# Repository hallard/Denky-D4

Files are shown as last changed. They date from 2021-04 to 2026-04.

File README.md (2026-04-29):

# Denky D4 ESP32 Teleinfo

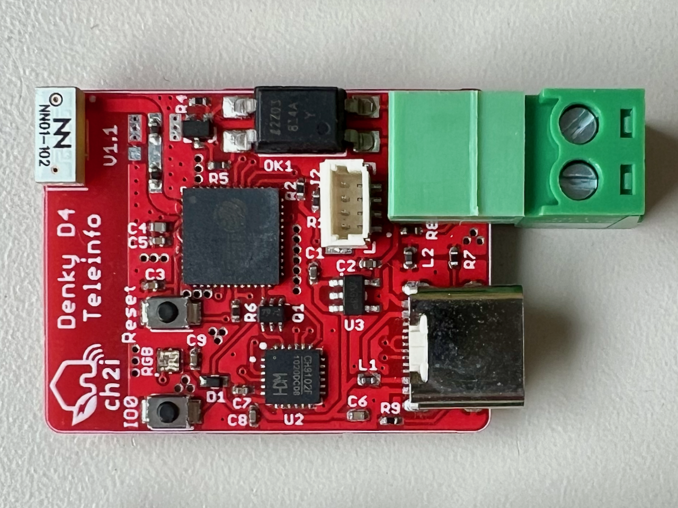
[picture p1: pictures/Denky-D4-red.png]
Denky D4


This board is used to get French energy meter called Teleinfo (AKA TIC) and has the following features:

- Steroid ESP32 using ESP32-PICO-V3-02 chip with 8Mb Flash and 2Mb PSRAM
- Serial to USB onboard converter
- Teleinfo Reader interface
- RGB User Led
- Blue LED to see if Teleinfo signal is received
- QWIIC/STEMMA I2C header sensors connector
- USB-C Connector

It is a plug and play board, nothing to solder or assemble.

# History

**New in v1.3a**

- Changed TIC trimmer from 1K to 2K
- Changed TIC Led (blue) resistor to decrease light intensity
- Placed easy cutting trace to disable Teleinfo Blue LED
- Added exposed pad for 5V and GND to external powering out of USB connector

**v1.3**

- Changed some silk for better reading

**v1.2**

- Replaced R3 by a trimmer to allow TIC sensitivity change without soldering resistors

**v1.1**

- Changed CPU now use ESP32-PICO-V3-02 with 8Mb Flash and 2Mb PSRAM
- Changed USB/SERIAL chip to CH9102 due to shortage
- Added footprint for U-FL connector for external antenna 
- Removed headers pins
- Reduced RGB LED size using SK6805-1515
- Added small visual blue LED on Teleinfo receive signal
- All components on same side (nothing on bottom side)

**v1.0**

- First fully working prototype

# Detailed Description

Look at the schematics for more informations, easy to understand. Wiring is as follow:

| Pin Function | ESP32-PICO | 
|  :--- |  :---:  |
| Téléinfo Rx  |  GPIO8  | 
| RGB Led |  GPIO14 | 
| I2C SDA |  GPIO21 | 
| I2C SDL |  GPIO22 | 

# Schematics

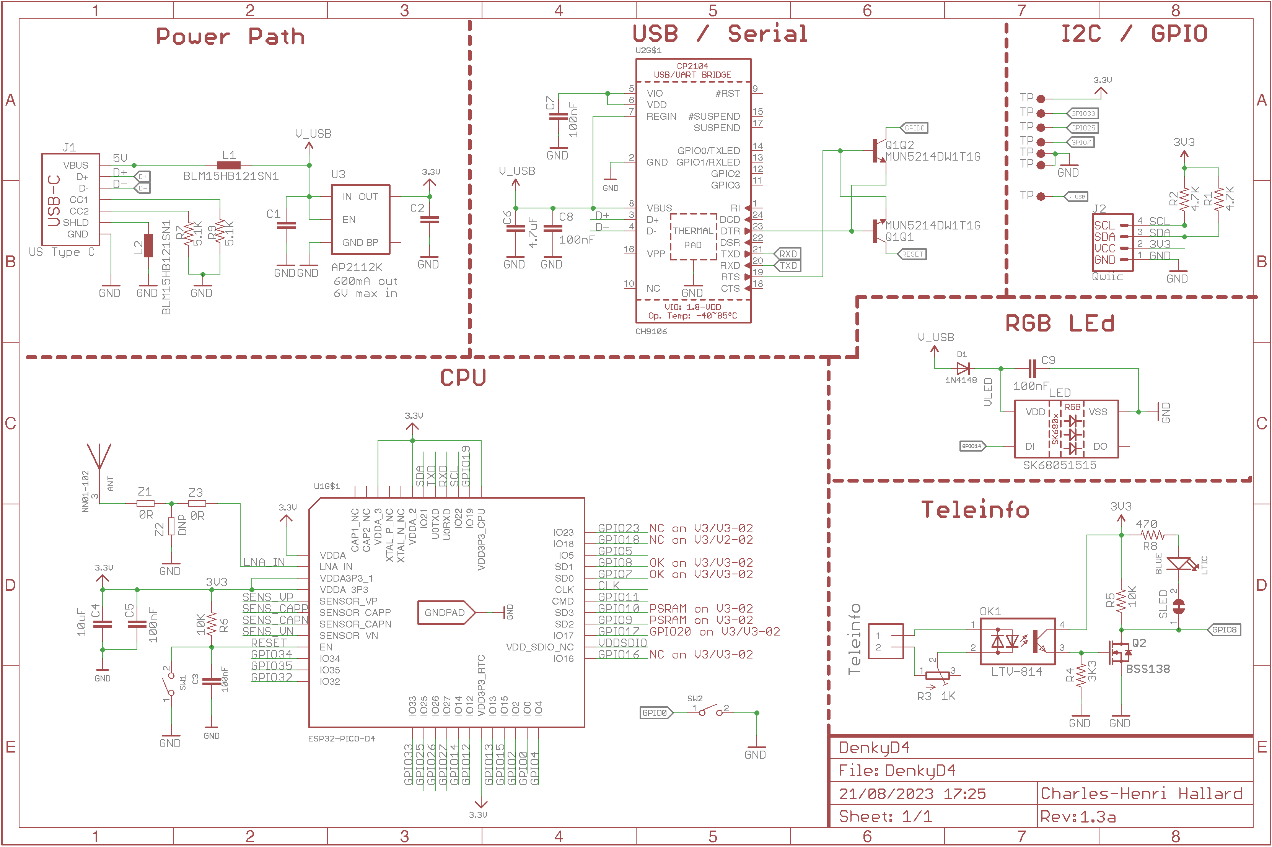
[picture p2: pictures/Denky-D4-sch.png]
Denky D4 Schematics


# Boards

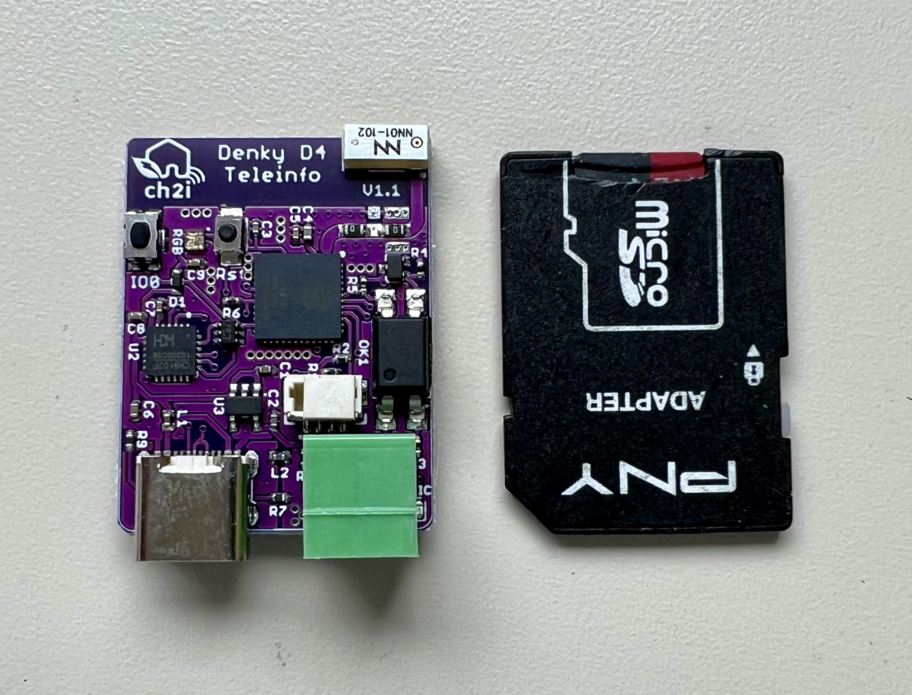
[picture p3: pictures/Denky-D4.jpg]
Denky D4 Size


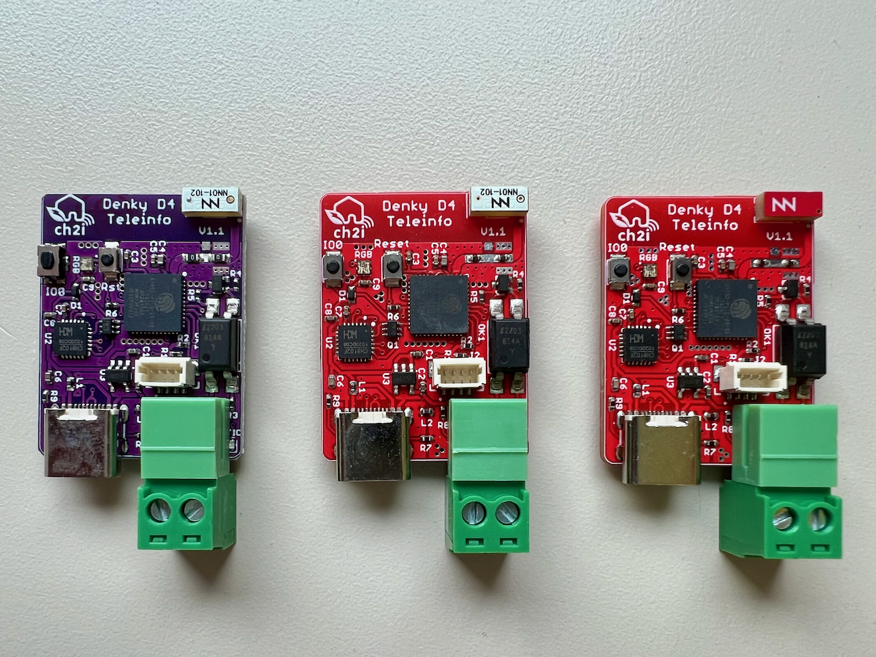
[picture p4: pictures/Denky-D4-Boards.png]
Denky D4 Boards


# Firmware 

It's compatible with Arduino IDE, Visual Studio Code and also Micro Python since this board use same CPU than Adafruit [QT-PY-ESP32-PICO](https://learn.adafruit.com/adafruit-qt-py-esp32-pico)

You can write your own and use with [LibTeleinfo](https://github.com/hallard/LibTeleinfo) library I wrote if you want to get rid of driving teleinfo stuff (chekout some [examples](ttps://github.com/hallard/LibTeleinfo/tree/master/examples)).

## Tasmota

But I strongly suggest using amazing [Tasmota](https://tasmota.github.io/docs/) firmware, all is already done and well done.

Please check Teleinfo official tasmota [documentation](https://tasmota.github.io/docs/Teleinfo/) so see how to configure your device depending on smartmeter type and what options you need.

### Nicolas's builds

Nicolas @NicolasBernaerts has made awesome changes on Tasmota to be able to show graph of consumption, history and other great features such has:

- Ecowatt server to publish RTE Ecowatt signals
- TCP server to live stream teleinfo data
- FTP server to easily retrieve graph data

You can find more information on his dedicated [repo](https://github.com/NicolasBernaerts/tasmota/tree/master/teleinfo) and also ready made build for this Denky D4 board.

### Tasmota Unofficial builds

Teleinfo is not member of official Tasmota builds. So you need to build your own with `USE_TELEINFO` define. 
But Tasmota team agreed it's not simple to build for end users, and they now provide unofficial build that follow developement branch, this mean you always have an up to date build with latest code available. Of course we added Teleinfo (ESP8266 and ESP32) builds in this unofficial build process so you have nothing to install and compile/link (building). You can't go easier.

And as a cherry on the cake, easy flasher tools (web version and executable one) will present Teleinfo firmware so you are able to flash teleinfo firmware in less than 1 minute. You can check detail [here](https://github.com/Jason2866/Tasmota-specials) but here how to do that.

- Launch [Web Flasher here](https://jason2866.github.io/Tasmota-specials/) 
- Select Teleinfo 
- Select Serial port, and click `install`



Once done something like that



After flashed, you should now see a new access point named `tasmota_aabbcc_xxxx` where you can connect to configure your WiFi for the device to connect on.

Alternatively, if you connect serial console and reset the device you should see Serial logs like that
```
00:00:00.003 HDW: ESP32-D0WDQ6 
00:00:00.037 UFS: FlashFS mounted with 308 kB free
00:00:00.109 CFG: Loaded from File, Count 12
00:00:00.124 QPC: Count 1
00:00:00.257 CFG: no '*.autoconf' file found
00:00:00.263 BRY: Berry initialized, RAM used=3620
00:00:00.282 BRY: no 'preinit.be'
00:00:00.291 Project tasmota - Tasmota Version 10.0.0.3(teleinfo)-2_0_1_1(2021-11-30T14:22:47)
00:00:00.379 BRY: no 'autoexec.be'
00:00:00.447 WIF: WifiManager active for 3 minutes
00:00:01.139 HTP: Web server active on tasmota-090F8C-3980 with IP address 192.168.4.1
00:00:06.827 QPC: Reset
```

If you want to deep into this process or just curious, you can check out it's [here](https://github.com/Jason2866/Tasmota-specials)

:memo: If you have some issues flashing with Web Flasher, do not hesitate to use another awesome tool [ESP Flasher](https://github.com/Jason2866/ESP_Flasher), with this one you can see exactly what's going on in case of issue because it has built in console. Usefull also after reboot of the device because console still active. This is the one I'm using day by day. In this case you need to download firmware to flash first [here](https://github.com/Jason2866/Tasmota-specials/tree/firmware/firmware/tasmota/other). Download firmware `tasmota-teleinfo`

You can take a look on `autoconf` [folder](https://github.com/tasmota/autoconf/tree/main/raw/esp32/Wemos_Teleinfo) to see some of init commands used on Denky D4.

:memo: Don't forget to reset Energy counters on first boot with console command `EnergyTotal 0` if you have erratic values. 

### I2C Display

You can add fancy I2C display (or even I2C sensors), using the on board QWIIC sensor, please refer to section [I2C Display](https://github.com/hallard/WeMos-TIC/blob/master/README.md#i2c-display).

### Autoconf 

Another awesome feature of Tasmota is the ability to download configuration profile, and guess what, we done it for Denky D4, just go to configuration option, select Autoconfig and then choose in the list `Denky D4 V1.1` and here you are, ne need to copy/paste template, it's done by autoconfig.
If you want to deep into this process or just curious, you can check out it's [here](https://github.com/tasmota/autoconf)

### Tasmota template

I strongly suggest using awesome Tamsota autoconf feature but if you need Tasmota template for Denky D4, here it it

#### V1.1 and up
```json
{"NAME":"Denky D4 (v1.1)","GPIO":[32,0,0,0,1,0,0,0,0,1,1376,1,0,0,0,0,0,640,608,0,0,0,0,0,0,0,5632,0,0,0,0,0,0,0,0,0],"FLAG":0,"BASE":1}
```

#### V1.0
```json
{"NAME":"Denky D4 (v1.0)","GPIO":[32,0,0,0,1,0,0,0,0,1,0,1,0,0,0,0,0,640,608,0,0,450,449,448,0,0,5632,0,0,0,0,0,0,0,0,0],"FLAG":0,"BASE":1}
```

## Berry Scripting 

Now you can personalize code with [Berry language](https://tasmota.github.io/docs/Berry/). Check out some Berry samples [here](https://github.com/arendst/Tasmota/blob/development/tasmota/berry/examples/)

You can do that by going to Berry console from Tasmota WEB user interface.

### Drive RGB LED depending on actual power

Here is a Berry example, goal is to follow real time consumption driving on board RGB Led depending on current Power consumption (low green then going to red when reaching maximum current of your contract)

```python
#-
# example of using Berry script to change the led color
# accordingly to power consumption
# using Denky or WeMos Teleinfo (French Teleinfo reader)
-#

#- define the global symbol for reference -#
runcolor = nil

def runcolor()
  var max_contrat = 30 # contrat 30A
  var i = energy.current
  #print(i)
  var red = tasmota.scale_uint(int(i), 0, max_contrat, 0, 255)
  var green = 255 - red
  var channels = [red, green, 0]
  light.set({"channels":channels, "bri":64, "power":true})
  tasmota.set_timer(2000, runcolor)
end

#- run animation -#
runcolor()
```

### Send data to Emoncms with Berry 

What's magic with Berry is the ability to do basic stuff with data, in this example we will intercept MQTT send message by Energy driver, do some calc and send data to Emoncms every 15 seconds and also to drive RGB Led from Green (low load) to Red (approach max subscription)

Modifiy API key with your, and copy paste the following code into Berry Console. Tst and validate if all is okay for you.

Once all is fine, you paste the code into a file named `autoexec.be` on the Tasmota Filesystem so it will be executed each time Tasmota device starting.

#### Mode Historique (contrat heures creuses)

```python
import json

var api_url = "https://emoncms.org/input/post"
var api_key = "YOUR_EMON_API_WRITE_KEY"
var node_name = "NODE_NAME"
var post_every = 15000 # post evert 15 seconds
var payload = {}

def send_emoncms()
  # Convert JSON object to string 
  var obj_json = json.dump(payload)

  # Create URL to call
  var param="?fulljson="+obj_json + "&node="+node_name + "&apikey="+api_key 
  # Post Data to EMONCMS
  var cl = webclient()
  cl.begin( api_url + param)
  var r =  cl.GET()
  tasmota.set_timer(post_every, send_emoncms)
end

def setcolor(iinst, isousc)
  var red = tasmota.scale_uint(iinst, 0, isousc, 0, 255)
  var green = 255 - red
  var channels = [red, green, 0]
  light.set({"channels":channels, "bri":64, "power":true})
end

# set global payload the field we need
def rule_tic(value, trigger)
  # Got Heures Creuses contract so I will calculate total consumption
  # adding Heures Creuses (HCHC) + Heures Pleines (HCHP) and create new value for emoncms 
  # Change label depending on name for your contract type
  var htot = value['HCHP'] + value['HCHC'] # mode historique
  # Create new value HTOT converted to kWH
  payload['HTOT'] = htot / 1000.0
  # Calculate current percent Load 
  var iinst = value['IINST']  # mode historique
  var isousc= value['ISOUSC'] # mode historique

  if iinst != nil && isousc != nil 
    # Drive RGB LED
    setcolor(iinst, isousc)
    if isousc > 0
      load = 100 * iinst / isousc
      payload['LOAD'] = load
    end
  end

  # Set values we need to send to emoncms
  payload['ADCO']  = value['ADCO']
  payload['HCHP']  = value['HCHP']
  payload['HCHC']  = value['HCHC']
  payload['ISOUSC']= isousc
  payload['PAPP']  = value['PAPP']
  payload['IINST'] = iinst

end

def start()
  # Callback on each frame interception
  tasmota.add_rule("TIC",rule_tic)
  # fire 1st post in 5s 
  tasmota.set_timer(5000, send_emoncms)
end

# delay start to have time to get full frame
tasmota.set_timer(10000, start)

```

#### Mode Standard (contrat heures creuses)

```python
import json

var api_url = "https://emoncms.org/input/post"
var api_key = "YOUR_EMON_API_WRITE_KEY"
var node_name = "NODE_NAME"
var post_every = 15000 # post evert 15 seconds
var payload = {}

def send_emoncms()
  # Convert JSON object to string 
  var obj_json = json.dump(payload)

  # Create URL to call
  var param="?fulljson="+obj_json + "&node="+node_name + "&apikey="+api_key 
  # Post Data to EMONCMS
  var cl = webclient()
  cl.begin( api_url + param)
  var r =  cl.GET()
  tasmota.set_timer(post_every, send_emoncms)
end

def setcolor(iinst, isousc)
  var red = tasmota.scale_uint(iinst, 0, isousc, 0, 255)
  var green = 255 - red
  var channels = [red, green, 0]
  light.set({"channels":channels, "bri":64, "power":true})
end

# set global payload the field we need
def rule_tic(value, trigger)
  # Got Heures Creuses contract so I will calculate total consumption
  # Calculate current percent Load 
  var iinst = value['IRMS1']  
  var isousc= value['PREF']*5 

  if iinst != nil && isousc != nil 
    # Drive RGB LED
    setcolor(iinst, isousc)
    if isousc > 0
      load = 100 * iinst / isousc
      payload['LOAD'] = load
    end
  end

  # Here I keep name of historique mode
  payload['ADCO']  = value['ADSC']
  payload['HTOT']  = value['EAST'] / 1000 # I need kWh
  payload['HCHP']  = value['EASF01']
  payload['HCHC']  = value['EASF02']
  payload['ISOUSC']= isousc
  payload['PAPP']  = value['SINSTS']
  payload['IINST'] = iinst

end

def start()
  # Callback on each frame interception
  tasmota.add_rule("TIC",rule_tic)
  # fire 1st post in 5s 
  tasmota.set_timer(5000, send_emoncms)
end

# delay start to have time to get full frame
tasmota.set_timer(10000, start)

```

### Custom WEB Interface

If you are not happy with values on the WEB interface you can totaly change them to fit your needs.

You can add new values to display or disable all values displayed and use you own or even some calculated ones.

To disable all current values displayed please use the following command in console (not the berry one)

```
backlog0 WebSensor0 0 ; WebSensor1 0 ; WebSensor2 0 ; WebSensor3 0
```

Then you can add Teleinfo driver (this one as example) into a file named `teleinfo.be`

This is just an example please fill it to your needs. This one display Total `EAST` index, `URMS1` and `IRMS1` on web interface

```python
# Teleinfo driver written in Berry
# Support for Teleinfo custom values from choosen fields returned by smart meter
 
class TELEINFO: Driver

  # Global var Needed
  var east
  var irms
  var urms

  def init()
    # initialize globals

    # Don't display original sensors on WebUI, we want just our ones
    tasmota.cmd("backlog0 WebSensor0 0 ; WebSensor1 0 ; WebSensor2 0 ; WebSensor3 0")

    # create rules to trigger when Teleinfo values updates 
    # Use Teleinfo Etiquette Names to get whatever value you need
    tasmota.add_rule("TIC#EAST", /value -> self.trigger_east(value))
    tasmota.add_rule("TIC#IRMS1", /value -> self.trigger_irms(value))
    tasmota.add_rule("TIC#URMS1", /value -> self.trigger_urms(value))
  end

  def trigger_east(index)
    self.east = index
  end

  def trigger_irms(i)
    self.irms = i
    # DEBUG print("irms:", i)
  end

  def trigger_urms(u)
    self.urms = u
    # DEBUG print("urms:", u)
  end

  # trigger a read every second 
  def every_second()
    # DEBUG print("sensors:",tasmota.read_sensors())
  end

  # display sensor value in the web UI
  def web_sensor()
    import string
    var msg = string.format(
            "{s}Consommation{m}%d Wh{e}"
            "{s}Tension RMS{m}%d V{e}"
            "{s}Intensité RMS{m}%d A{e}", 
             self.east, self.urms, self.irms )

    tasmota.web_send_decimal(msg)
  end

end

# Instantiate the driver
teleinfo = TELEINFO()
# add it to Tasmota
tasmota.add_driver(teleinfo)

```

Then you need to load and start it into your `autoexec.be` file. just add followin at the end of the file

```python
# Auto start teleinfo driver
load("teleinfo.be")
```

#### Here how it looks like

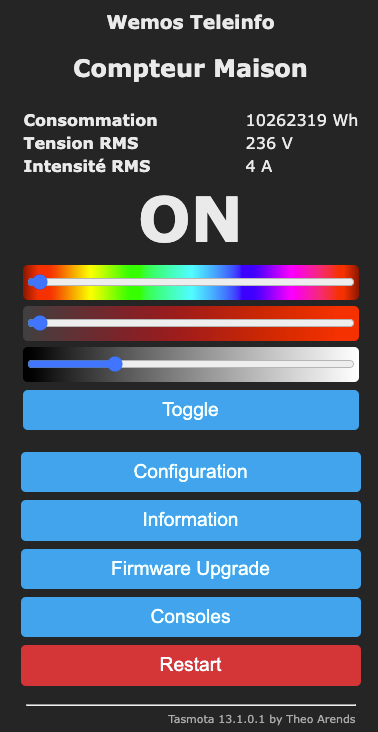
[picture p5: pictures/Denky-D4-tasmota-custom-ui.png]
Denky D4 Custom User Interface


### ESPHome

Denky D4 is fully compatible with ESPHome, find below a sample for Historique with Heures Creuses contract.
Pasting this code without knowing your contract and teleinfo mode of your linky will just NOT work, you need to adpat to your needs        

Read and get full working samples on @mathieucarbou [gist](https://gist.github.com/mathieucarbou/886d2a6f5c0b51bb261d6a1329beb08d#file-readme-md)

`denky-d4.yaml`

```yaml
# This code comes from @mathieucarbou many thanks to him
# you need to check it out and adapt depending on your needs
# https://gist.github.com/mathieucarbou/886d2a6f5c0b51bb261d6a1329beb08d#file-readme-md
# You need to knw wich mode your smart meter is (HISTORIQUE or STANDARD)
# and which contract you have to adjust sensor name to grab correct sensor information

esphome:
  name: denky-d4
  friendly_name: Denky D4

esp32:
  board: denky_d4
  framework:
    type: esp-idf

logger:
#  level: WARN

wifi:
  ssid: !secret wifi_ssid
  password: !secret wifi_password

api:

ota:
  platform: esphome

# Denky D4 RX pin
uart:
  rx_pin:
    number: GPIO8
    ignore_pin_validation_error: true
  baud_rate: 1200
  parity: EVEN
  data_bits: 7
  stop_bits: 1

binary_sensor:
  - platform: status
    id: teleinfo_status
    name: "Teleinfo Status"

button:
  - platform: restart
    name: "Teleinfo Restart"

# https://esphome.io/components/sensor/teleinfo.html
teleinfo:
  update_interval: 5s
  historical_mode: true

# Web Server: https://esphome.io/components/web_server.html
web_server:
  local: true
  port: 80    
    #   auth:
    #     username: !secret esphome_web_server_username
    #     password: !secret esphome_web_server_password

# https://esphome.io/components/sensor/index.html
sensor:
  # WiFi
  - platform: wifi_signal
    name: "WiFi Signal"
    unit_of_measurement: dB
    device_class: signal_strength
    accuracy_decimals: 0
    update_interval: 60s
  # Uptime
  - platform: uptime
    name: "Uptime"
    unit_of_measurement: s
    device_class: duration
    accuracy_decimals: 0
    update_interval: 60s

#######################################################
#      HISTORIQUE with Heures Creuses Contract        #
# Pasting this code without knowing your contract and #
# teleinfo mode of your linky will just NOT work      #
# YOu will need to adpat to your needs                #
#######################################################

  # Intensité souscrite
  - platform: teleinfo
    tag_name: "ISOUSC"
    name: "Intensité souscrite"
    unit_of_measurement: A
    device_class: current
    state_class: measurement
  # Index option Base
  #- platform: teleinfo
  # tag_name: "BASE"
  # name: "Index Base"
  # unit_of_measurement: kWh
  # device_class: energy
  # state_class: total_increasing
  # accuracy_decimals: 3
  # filters:
  #   - multiply: 0.001
  # Index option HP/HC
  - platform: teleinfo
    tag_name: "HCHC"
    name: "Index HC"
    unit_of_measurement: kWh
    device_class: energy
    state_class: total_increasing
    accuracy_decimals: 3
    filters:
      - multiply: 0.001
  - platform: teleinfo
    tag_name: "HCHP"
    name: "Index HP"
    unit_of_measurement: kWh
    device_class: energy
    state_class: total_increasing
    accuracy_decimals: 3
    filters:
      - multiply: 0.001

  # Intensité Instantanée (monophasé)
  - platform: teleinfo
    tag_name: "IINST"
    name: "Intensité Instantanée"
    unit_of_measurement: A
    device_class: current
    state_class: measurement
  # Avertissement de Dépassement De Puissance Souscrite
  - platform: teleinfo
    tag_name: "ADPS"
    name: "Intensité Instantanée Dépassement"
    unit_of_measurement: A
    device_class: current
    state_class: measurement
  # Intensité maximale appelée (monophasé)
  - platform: teleinfo
    tag_name: "IMAX"
    name: "Intensité Maximale"
    unit_of_measurement: A
    device_class: current
    state_class: measurement
  # Puissance apparente
  - platform: teleinfo
    tag_name: "PAPP"
    name: "Puissance Apparente"
    unit_of_measurement: VA
    state_class: measurement
    device_class: apparent_power

# https://esphome.io/components/text_sensor/index.html
text_sensor:
  # Adresse du compteur
  - platform: teleinfo
    tag_name: "ADCO"
    name: "Adresse"
  # Option tarifaire choisie
  - platform: teleinfo
    tag_name: "OPTARIF"
    name: "Option Tarifaire"
  # Période Tarifaire en cours
  - platform: teleinfo
    tag_name: "PTEC"
    name: "Période Tarifaire"
  # Couleur du lendemain
  - platform: teleinfo
    tag_name: "DEMAIN"
    name: "Couleur Demain"
  # Horaire Heures Pleines Heures Creuses
  - platform: teleinfo
    tag_name: "HHPHC"
    name: "Horaire HP/HC"
  # Mot d'état du compteur
  - platform: teleinfo
    tag_name: "MOTDETAT"
    name: "Mot d'état"

```

# Support and discussion

If you have any issue or just want to discuss on this project, please use community [forum](https://community.ch2i.eu/category/20)

# License



This work is licensed under a [Creative Commons Attribution-NonCommercial-ShareAlike 4.0 International License](https://creativecommons.org/licenses/by-nc-sa/4.0/)    
If you want to do commercial stuff with this project, please contact [CH2i company](https://ch2i.eu/en#support) so we can organize an simple agreement.

# Lazy building your own? 

You can order this module (V1.3a only) fully assembled with some extra on [tindie][1] or on [Lectronz](https://lectronz.com/products/denky-d4).

European customers may prefer ordering on Lectronz, which offers additional payment methods and pricing in Euros.





# Misc

See news and other projects on my [blog][2] 
 
[1]: https://www.tindie.com/products/25467/
[2]: https://hallard.me

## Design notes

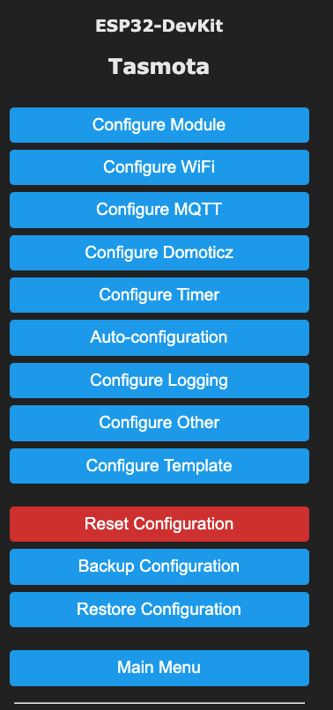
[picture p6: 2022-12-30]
pictures/Denky-D4-tasmota-config.png

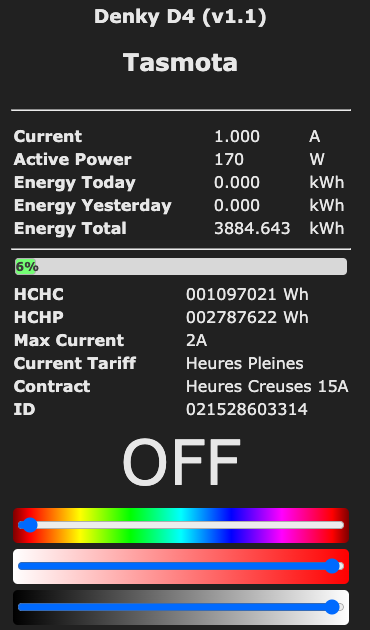
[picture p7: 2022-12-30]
pictures/Denky-D4-tasmota-ok.png

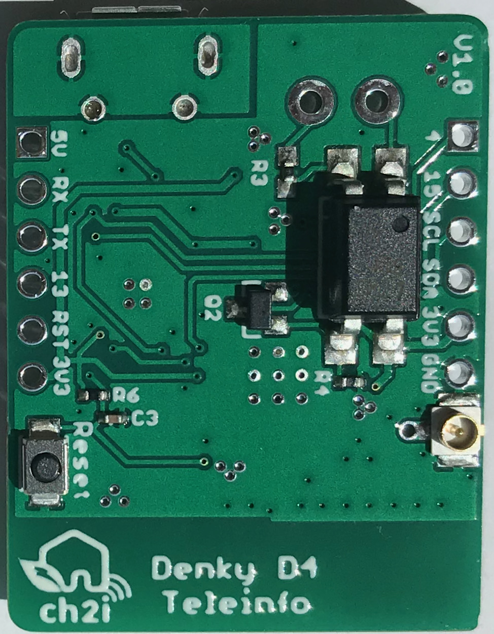
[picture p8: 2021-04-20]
pictures/denky-d4-bot.jpg

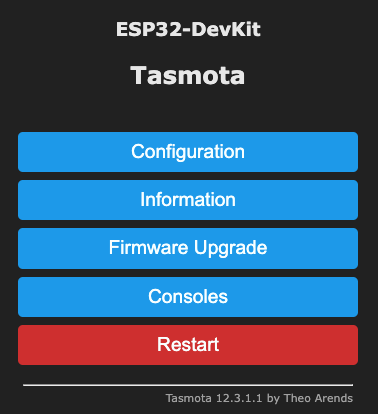
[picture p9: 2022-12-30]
pictures/Denky-D4-tasmota-boot.png

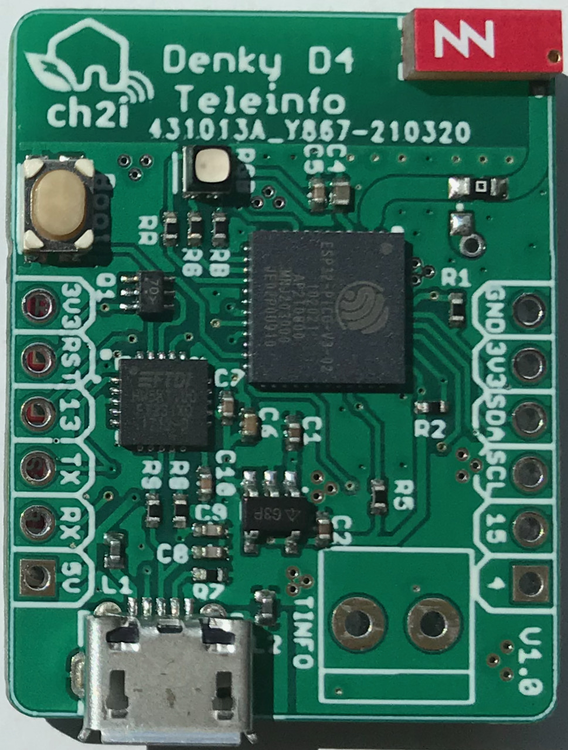
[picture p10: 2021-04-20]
pictures/denky-d4-top.jpg

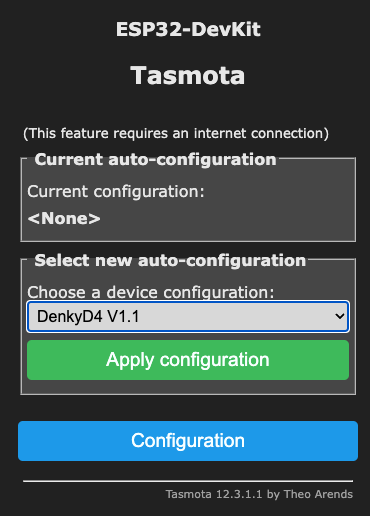
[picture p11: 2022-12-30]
pictures/Denky-D4-tasmota-auto-config.png

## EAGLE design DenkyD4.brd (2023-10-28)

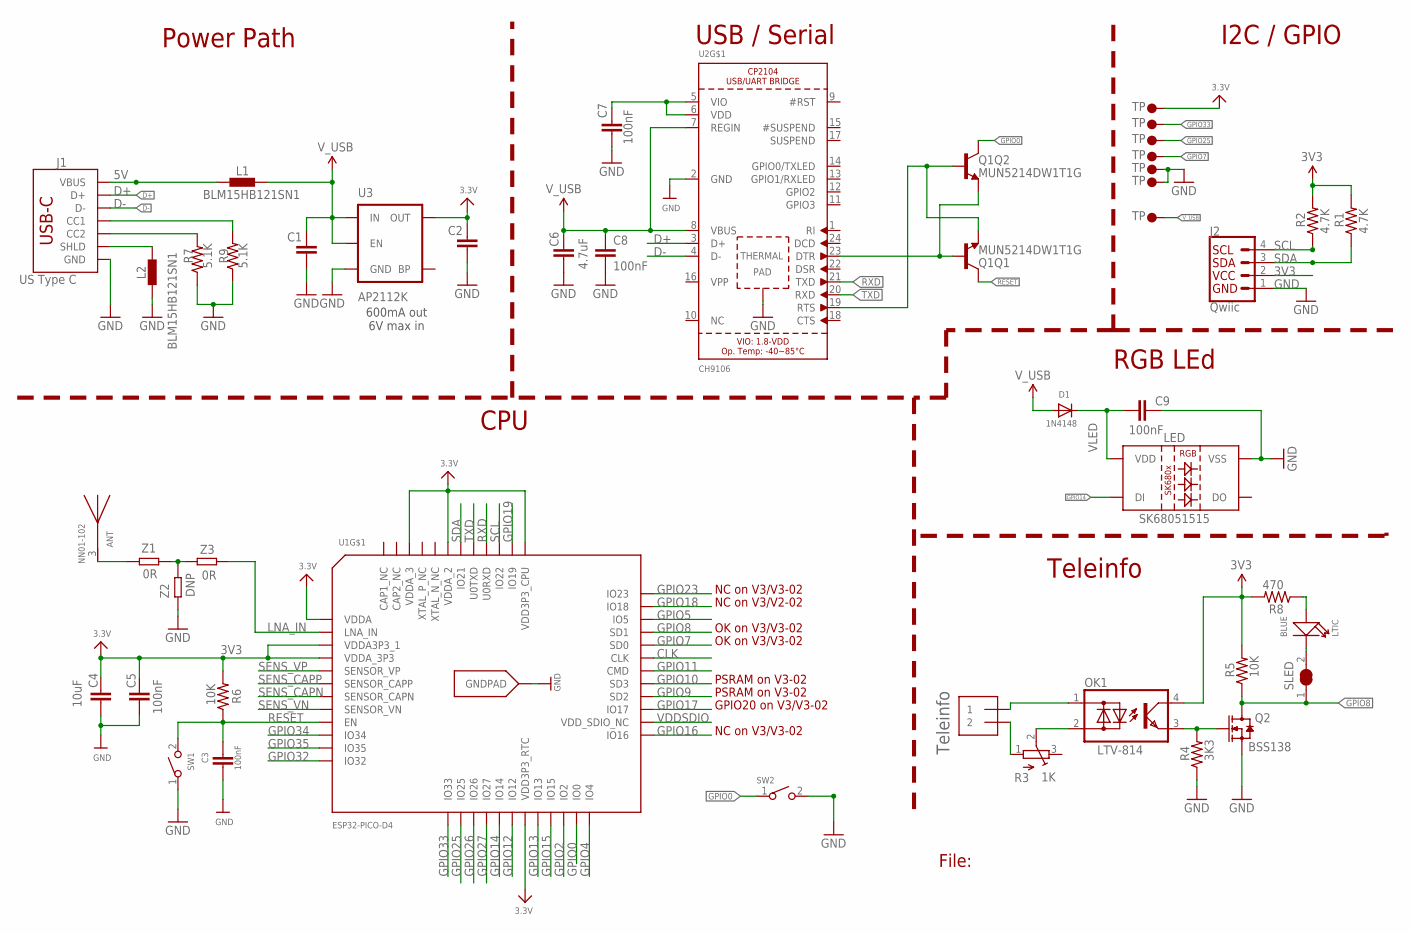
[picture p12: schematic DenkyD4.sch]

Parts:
ANT: NN01-102; XCVR_NN03-320
C1, C2: 1.0uF; 0402-CAP-OK
C3, C5, C7, C8, C9: 100nF; 0402-CAP-OK
C4: 10uF; 0402-CAP-OK
C6: 4.7uF; 0402-CAP-OK
D1: 1N4148; SOD-523
J1: US Type C; USB-C-16P-4LAYER-ISOLATED
J2: Qwiic; JST04_1MM_VERT
J3: KF2EDGR-3.81-2P; 1X2-3.5MM
L1, L2: BLM15HB121SN1; 0402
LED: SK68051515; SK6805-1515
LTIC: BLUE; LED-0402
OK1: LTV-814; DIL4-SMD
Q1: MUN5214DW1T1G; DUAL_NPN_SC70-6
Q2: BSS138; SOT-323-3
R1, R2: 4.7K; 0402-RES
R3: 1K; TC33X
R4: 3K3; 0402-RES
R5, R6: 10K; 0402-RES
R7, R9: 5.1K; 0402-RES
R8: 470; 0402-RES
SLED: SOLDERJUMPER_CLOSED; SOLDERJUMPER_CLOSEDWIRE
SW1: RESET; C498294
SW2: SMD-BUTTON(2P-3.0X2.5X1.2+0.4MM); C498294
TGG, TGG1, TGG2: TP3; TP60_BOT
TP3: TP3; TP60_BOT
U1: ESP32-PICO-D4; PICO-D4-QFN48
U2: CH9106; QFN24_4MM_SMSC
U3: AP2112K; SOT23-5
U$3, U$6, U$11: TP3; TP60_BOT
Z1, Z3: 0R; 0603-MATCHNET
Z2: DNP; 0603-MATCHNET

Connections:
3V3: C2.1, C4.1, C5.1, J2.2, OK1.4 (C), R1.2, R2.2, R5.2, R6.2, R8.2, TP3.P$1, U1.1 (VDDA), U1.3 (VDDA3P3_1), U1.4 (VDDA_3P3), U1.19 (VDD3P3_RTC), U1.37 (VDD3P3_CPU), U1.43 (VDDA_2), U1.46 (VDDA_3), U3.5 (OUT)
5V: J1.VBUS1 (VBUS), J1.VBUS2 (VBUS), L1.1
CLK: U1.31 (CLK)
D+: J1.A6 (D+), J1.B6 (D+), U2.3 (D+)
D-: J1.A7 (D-), J1.B7 (D-), U2.4 (D-)
DTR: Q1.1 (E), Q1.5 (B), U2.23 (DTR)
GND: C1.2, C2.2, C3.2, C4.2, C5.2, C6.1, C7.1, C8.2, C9.2, J1.GND, J1.GND2 (GND), J2.1, L2.2, LED.4 (VSS), Q2.2 (S), R4.1, R7.1, R9.1, SW1.1, SW2.2, TGG.P$1, TGG1.P$1, U1.EXP (GNDPAD), U2.2 (GND), U2.THERM (TP), U3.2 (GND), Z2.2
GPIO0: Q1.6 (C), SW2.1, U1.23 (IO0)
GPIO2: U1.22 (IO2)
GPIO4: U1.24 (IO4)
GPIO5: U1.34 (IO5)
GPIO7: U1.32 (SD0), U$3.P$1
GPIO8: Q2.3 (D), R5.1, SLED.1, U1.33 (SD1)
GPIO9: U1.28 (SD2)
GPIO10: U1.29 (SD3)
GPIO11: U1.30 (CMD)
GPIO12: U1.18 (IO12)
GPIO13: U1.20 (IO13)
GPIO14: LED.1 (DI), U1.17 (IO14)
GPIO15: U1.21 (IO15)
GPIO16: U1.25 (IO16)
GPIO17: U1.27 (IO17)
GPIO18: U1.35 (IO18)
GPIO19: U1.38 (IO19)
GPIO23: U1.36 (IO23)
GPIO25: U1.14 (IO25), U$11.P$1
GPIO26: U1.15 (IO26)
GPIO27: U1.16 (IO27)
GPIO32: U1.12 (IO32)
GPIO33: U1.13 (IO33), U$6.P$1
GPIO34: U1.10 (IO34)
GPIO35: U1.11 (IO35)
LNA_IN: U1.2 (LNA_IN), Z3.2
unnamed: Z1.1, Z2.1, Z3.1
unnamed: OK1.3 (E), Q2.1 (G), R4.2
unnamed: OK1.2 (AC2), R3.2 (S)
unnamed: J3.1, OK1.1 (AC1)
unnamed: J3.2, R3.1 (A)
unnamed: LTIC.-, SLED.2
unnamed: C7.2, U2.5 (VIO), U2.6 (VDD)
unnamed: LTIC.+, R8.1
unnamed: J1.A5 (CC1), R9.2
unnamed: J1.B5 (CC2), R7.2
unnamed: ANT.3, Z1.2
RESET: C3.1, Q1.3 (C), R6.1, SW1.2, U1.9 (EN)
RTS: Q1.2 (B), Q1.4 (E), U2.19 (RTS)
RXD: U1.40 (U0RXD), U2.21 (TXD)
SCL: J2.4, R2.1, U1.39 (IO22)
SDA: J2.3, R1.1, U1.42 (IO21)
SENS_CAPN: U1.7 (SENSOR_CAPN)
SENS_CAPP: U1.6 (SENSOR_CAPP)
SENS_VN: U1.8 (SENSOR_VN)
SENS_VP: U1.5 (SENSOR_VP)
SHIELD: J1.SHLD1 (SHLD), J1.SHLD2 (SHLD), J1.SHLD3 (SHLD), J1.SHLD4 (SHLD), J1.SHLD5 (SHLD), J1.SHLD6 (SHLD), J1.SHLD7 (SHLD), J1.SHLD8 (SHLD), L2.1
TXD: U1.41 (U0TXD), U2.20 (RXD)
VDDSDIO: U1.26 (VDD_SDIO_NC)
VLED: C9.1, D1.K (C), LED.2 (VDD)
V_USB: C1.1, C6.2, C8.1, D1.A, L1.2, TGG2.P$1, U2.7 (REGIN), U2.8 (VBUS), U3.1 (IN), U3.3 (EN)

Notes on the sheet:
File:
Teleinfo
I2C / GPIO
600mA out 6V max in
GPIO20 on V3/V3-02
NC on V3/V3-02
PSRAM on V3-02
OK on V3/V3-02
NC on V3/V2-02
RGB LEd
USB / Serial
Power Path
CPU

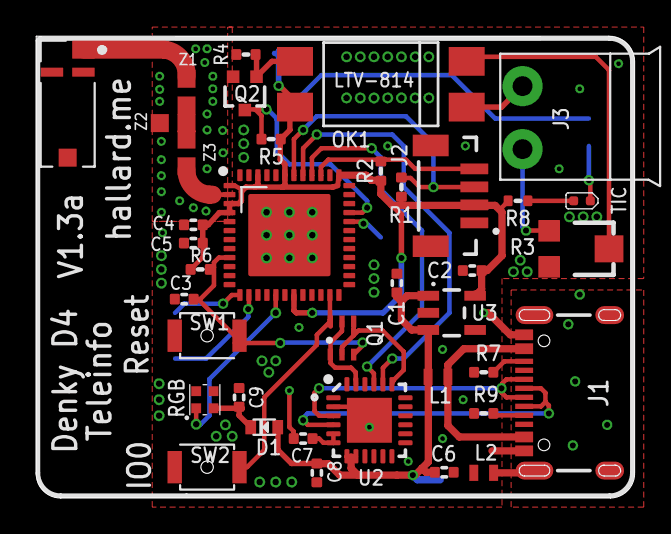
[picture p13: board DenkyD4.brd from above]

Board: 2 copper layers, 33.2 x 25.7 mm, 46 parts (1 on the bottom side), 33 nets.

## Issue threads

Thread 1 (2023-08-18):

Auto alimentation

cosygarcia, 2023-08-18:
Bonjour Charles,
Félicitation pour cette belle réalisation qu'est le Denky D4.
Dans le cas d’un compteur Linky à l’extérieur de la maison comment faudrait-il faire pour utiliser la borne A du Linky pour alimenter le Denky D4 ?
Merci d’avance

hallard, 2023-10-28:
Bonjour,
C'est en cours avec Jérôme on travaille sur une nouvelle version :-)
https://gricad-gitlab.univ-grenoble-alpes.fr/ferrarij/winky

Closed 2023-10-28.

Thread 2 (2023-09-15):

Compat avec ESPHome

alucryd, 2023-09-15:
Bonjour,

Je viens juste de commander un D4, il semble que le bug suivant pourrait être gênant si je flashe ESPHome dessus: https://github.com/esphome/issues/issues/4151

Je peux répliquer dans l'éditeur, par contre si je sélectionne `adafruit_qtpy_esp32` comme board je n'ai plus d'erreur. Est-ce que ça a déja pu être testé, histoire que je ne fasse pas n'importe quoi ?

hallard, 2023-10-28:
Bonjour oui je crois que la reponse est dans l'issue originale.

Sinon qq info ici et la  https://forum.hacf.fr/t/separer-les-heures-creuses-et-pleines-en-fonction-d-un-sensor/20164/17

Closed 2023-10-28.

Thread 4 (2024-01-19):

Power from Linky A Slot

xav-git, 2024-01-19:
Hello,
I did not find any information whether this module could be plugged directly on Linky  "A" pin in order to benefit from the power supply provided by linky power meters.

I assume that an independant power source would be needed to power this module, am I right ?
Regards.

hallard, 2024-01-19:
Hi,
you're correct, Denky D4 needs a power supply because Tasmota is running all time (real time reading/sending data).

Powered by A pin is not possible with Denky D4 because it's not it's main function but also because hardware is not designed for. Even if it was designed for, working mode would be different, sleeping until we have enough power, then connect to wifi send data and go to sleep again.
We're working on Winky version this one would be powered with A pin
https://miniprojets.net/index.php/2022/02/04/winky-version-2-open-source-projet-pour-linky-avec-wifi/

Closed 2024-02-01.

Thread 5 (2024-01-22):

Missing sensors in HA

jsapede, 2024-01-22:
Hello,

installed this weekend denky D4 and seems to work well with homeassistant.

Howevoer, in HA i got some sensors always to Zero :

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

looks like power is correctly upstreramed, an i build my own energy counters but what to do with those zero counters  ? is it normal ? its there a manipulation to do on the linky ?

Jimmy

hallard, 2024-08-19:
@jsapede sorry about delay, for home assistant you can use excellent firmware done by Nicolas, Home Assistant integration is native as others.
check this out https://github.com/NicolasBernaerts/tasmota/tree/master/teleinfo

Closed 2024-08-19.

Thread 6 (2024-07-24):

Denky power issue

nyok92, 2024-07-24:
Hi @hallard
My denky D4 board v1.3a bought in November 2023 is not powering up anymore. (no led lit, not detected with computer)
Do you have any tips to troubleshoot ? known issue ?
thanks

nyok92, 2024-07-24:
negative ! all is right sorry

Closed 2024-07-24.

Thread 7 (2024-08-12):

compatibility with Linky?

Abdull, 2024-08-12:
Dear Charles,

sorry if noob question (smart meters are implemented differently in Germany):

* is the Denky D4 compatible with French Linky boxes?
* if so, how would the be connected to a Linky box? Via connecting cables to the Linky box (when taking of its green cover) at its lower right corner? Could you provide example photos?
* Using a Teleinfo-enabled Tasmota firmware, is the Denky-D4 already self-sufficient for reporting current and historical data ,e.g. by visiting its own web interface? Or does it require a further separate home automation application, e.g. a dedicated Home Assistant installation, which connects to the Denky-D4 and pulls data?

Thanks in advance

hallard, 2024-08-19:
Hi @Abdull

>is the Denky D4 compatible with French Linky boxes?

yes fully compatible,

> if so, how would the be connected to a Linky box?

for pin it needs to be connected to pins I1 and I2 pins, no matter what sense it's not polarized. they are located under green cover (bottom right) but sometimes at other places see [here](https://www.google.com/search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)

> Using a Teleinfo-enabled Tasmota firmware, is the Denky-D4 already self-sufficient for reporting current and historical data

I suggest using latest Nicolas firmware, rocks and have some onboard graphics history if you don't want to use a separate home automation system.
https://github.com/NicolasBernaerts/tasmota/tree/master/teleinfo

Closed 2024-08-19.

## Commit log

2021-04-20 replace 220Ohm R3 from 0402 to 0603
    [Bom-DenkyD4.xlsx]
2021-04-20 prepare to v1.1 version
    [DenkyD4.brd]
2022-12-30 Updated to V1.2
    [DenkyD4.brd, DenkyD4.sch]
2023-01-02 Bump to V1.2
    [DenkyD4.brd, DenkyD4.sch]
2023-10-28 Bump to V1.3a
    [DenkyD4.brd, DenkyD4.sch]
2023-10-28 remove gerbers
2026-02-11 Added ESPHome documentation and sample
    Added ESPHome documentation and sample
2026-04-29 Switch to CC BY-NC-SA 4.0 license, add LICENSE file

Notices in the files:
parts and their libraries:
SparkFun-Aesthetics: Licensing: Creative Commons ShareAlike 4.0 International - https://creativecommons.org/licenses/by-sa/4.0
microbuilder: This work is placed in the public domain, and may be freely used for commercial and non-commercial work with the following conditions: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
